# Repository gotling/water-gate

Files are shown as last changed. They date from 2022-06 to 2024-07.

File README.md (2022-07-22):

# Watergate

A growhose helper. Sensors and watering of plants with added nutrition. 

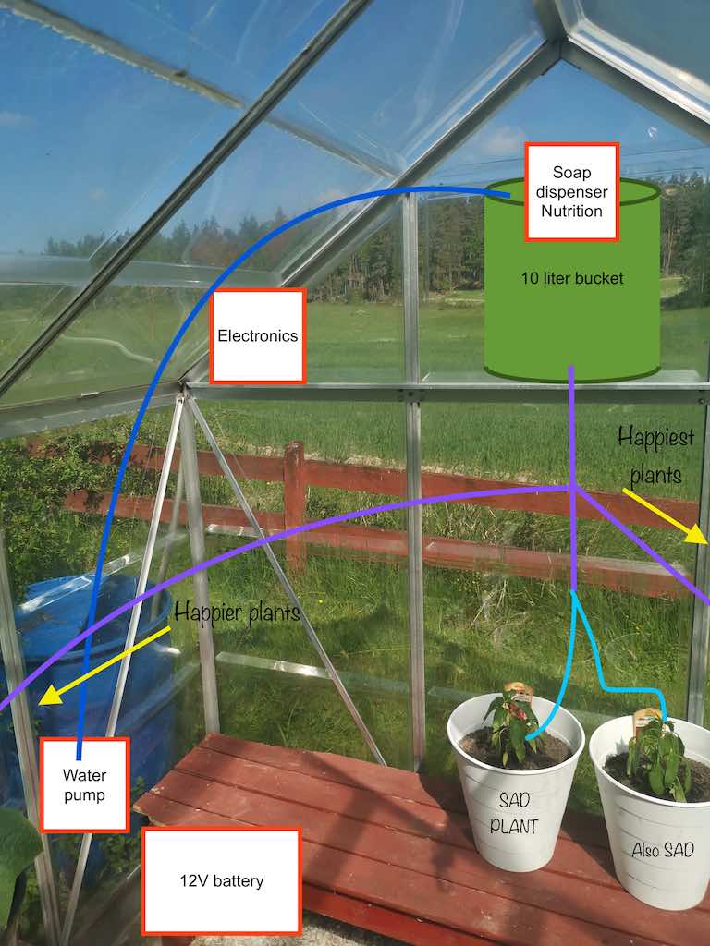
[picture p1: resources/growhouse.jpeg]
Growhouse


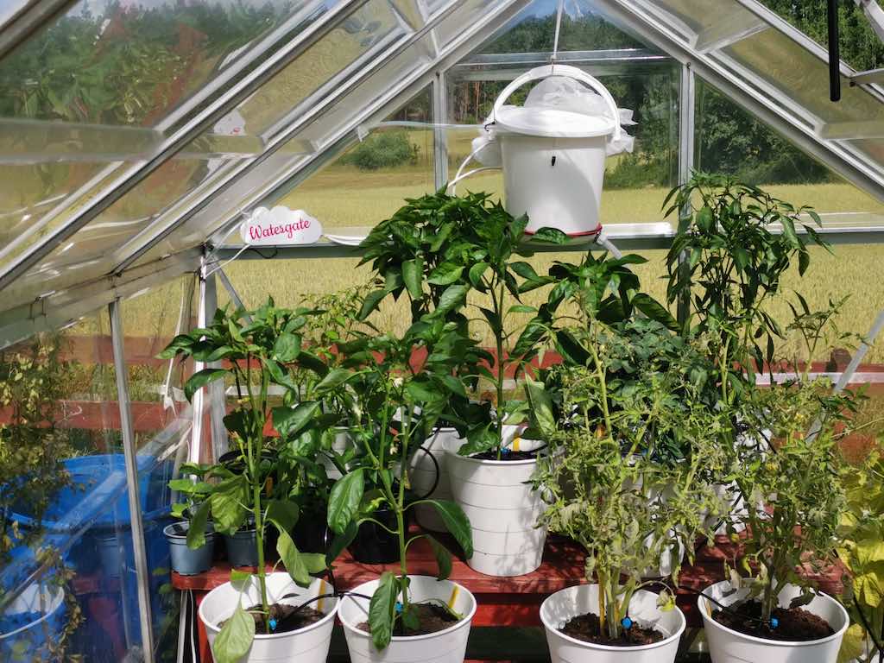
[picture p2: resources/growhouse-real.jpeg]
Growhouse Photo


# Configuration

WiFi config set using WiFi Manager by connecting to network Watergate on first boot.

**gmtOffset_sec**

Adjustment in seconds from GMT

**waterHour**

Array of hours when automatic watering should be done

## MQTT

Setup to use Adafruit IO service.

Configure username, password and topic by creating a *config.h* file with the following defines:

    #define MQTT_USER ""
    #define MQTT_PASSWORD ""
    #define MQTT_TOPIC ""

# Hardware

ESP32 devkit.

DHT22 temperature and humidity sensor.

12v AGM battery.

12v 5w water pump.

Hygrometers for measuring soil humidity.

Buck converter for getting 5v from 12v battery.

Simple voltage divider for checking battery level.

MOSFETs for controlling pump, motor and sensors.

Water level sensors.

# Schematics

First time using KiCad to help with construction.

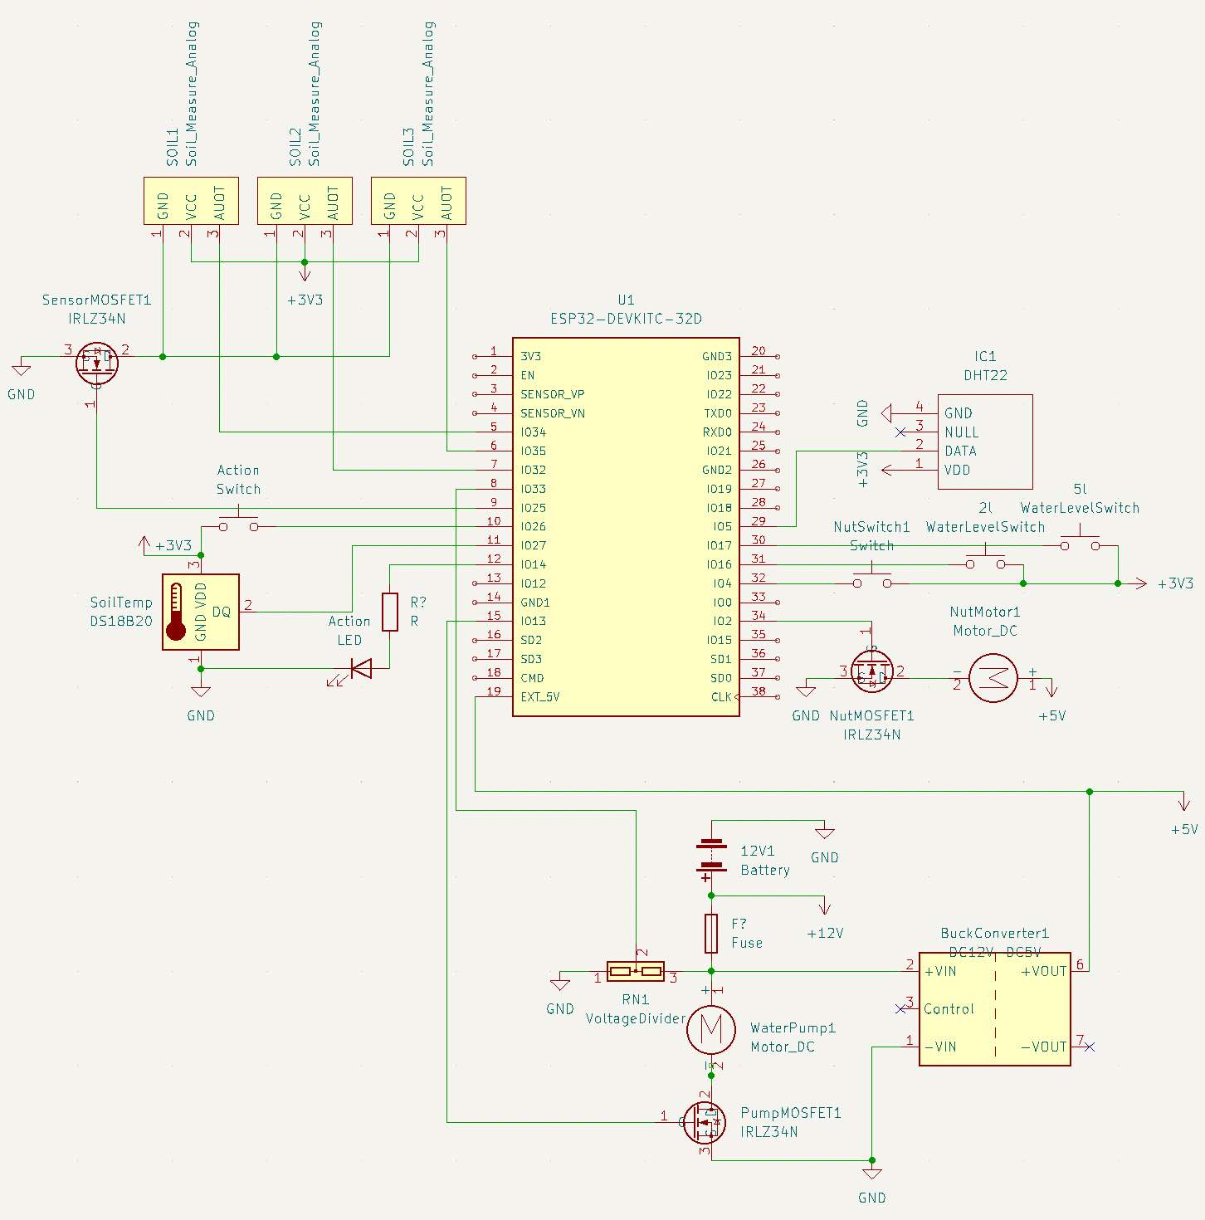
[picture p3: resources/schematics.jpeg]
Schematics


# Software

Written in Arduino IDE 2.0.

Coded in C.

# Enclosures

Made in Fusion 360 with main purpouse to protect electronics from direct sunligt.

https://a360.co/3csUwN7

# Libraries

These libraries needs to be installed in Arduino IDE to be able to build.

**FTDebouncer** by Ubi de Feo

https://github.com/ubidefeo/FTDebouncer

**DHT sensor library** by Adafruit

https://github.com/adafruit/DHT-sensor-library

**WiFiManager** by tzapu

https://github.com/tzapu/WiFiManager

**PubSubClient** by Nick O'Leary

https://github.com/knolleary/pubsubclient

**DallasTemperature** by Miles Burton

https://github.com/milesburton/Arduino-Temperature-Control-Library

**OneWire** by Jim Studt, ...

https://www.pjrc.com/teensy/td_libs_OneWire.html

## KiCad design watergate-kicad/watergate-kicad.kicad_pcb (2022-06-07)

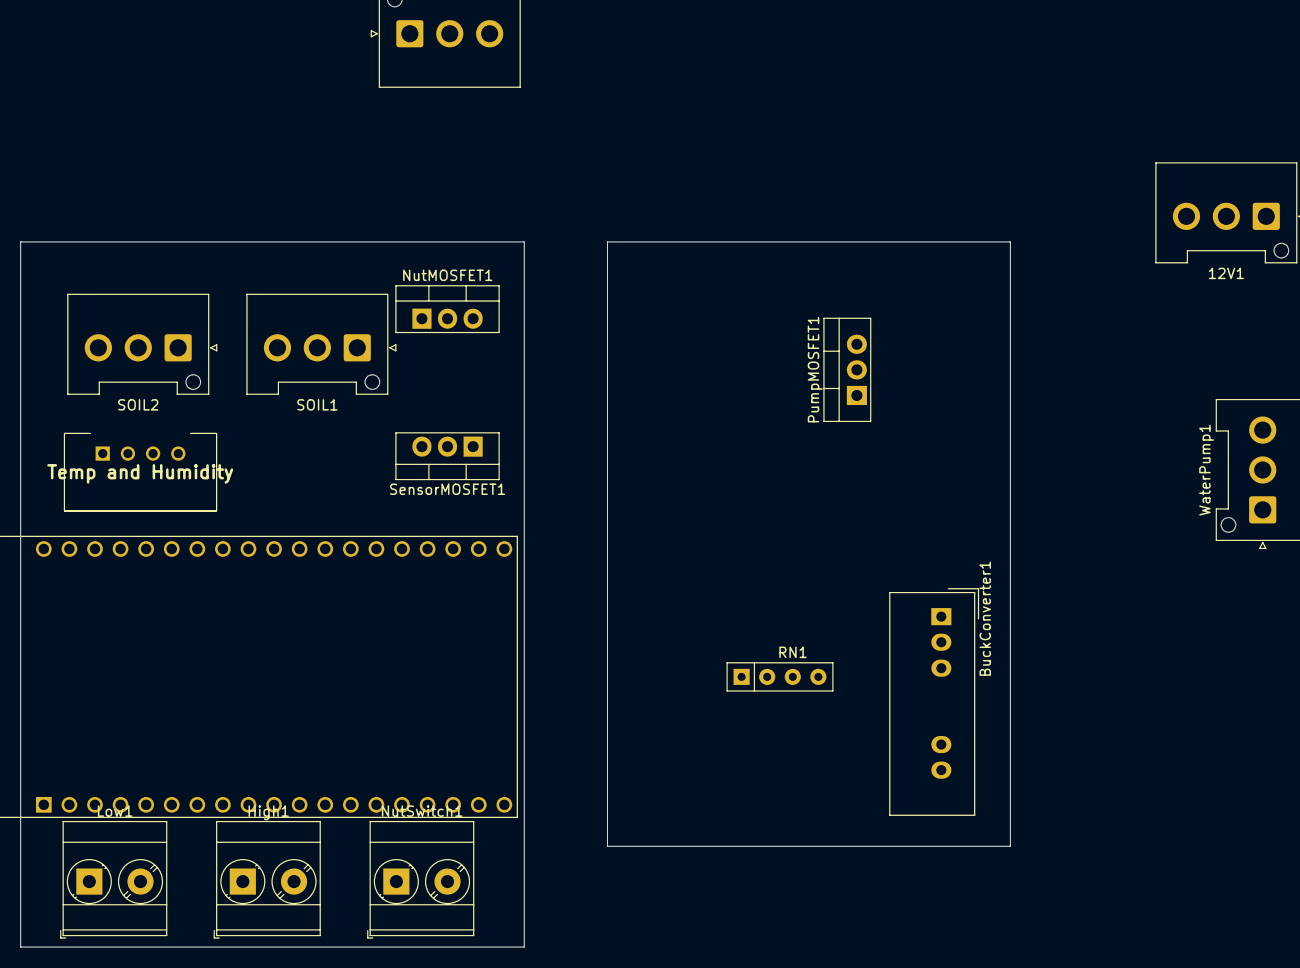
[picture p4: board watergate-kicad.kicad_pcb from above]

Board: 2 copper layers, 98.3 x 70.0 mm, 15 parts (0 on the bottom side), 18 nets, no tracks yet.

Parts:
12V1: Battery; JST_VH_B3P-VH-FB-B_1x03_P3.96mm_Vertical
BuckConverter1: DC12V-DC5V; Converter_DCDC_Murata_NCS1SxxxxSC_THT
High1: WaterLevelSwitch; TerminalBlock_Phoenix_MKDS-3-2-5.08_1x02_P5.08mm_Horizontal
Low1: WaterLevelSwitch; TerminalBlock_Phoenix_MKDS-3-2-5.08_1x02_P5.08mm_Horizontal
NutMOSFET1: IRLZ34N; TO-220-3_Vertical
NutMotor1: Motor_DC; JST_VH_B3P-VH-FB-B_1x03_P3.96mm_Vertical
NutSwitch1: Switch; TerminalBlock_Phoenix_MKDS-3-2-5.08_1x02_P5.08mm_Horizontal
PumpMOSFET1: IRLZ34N; TO-220-3_Vertical
RN1: VoltageDivider; R_Array_SIP4
SOIL1, SOIL2: Soil_Measure_Analog; JST_VH_B3P-VH-FB-B_1x03_P3.96mm_Vertical
SensorMOSFET1: IRLZ34N; TO-220-3_Vertical
Temp and Humidity: DHT22
U1: ESP32-DEVKITC-32D; MODULE_ESP32-DEVKITC-32D
WaterPump1: Motor_DC; JST_VH_B3P-VH-FB-B_1x03_P3.96mm_Vertical

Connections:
unnamed: 12V1.1 (+), BuckConverter1.2 (+VIN), RN1.3, WaterPump1.1 (+)
unnamed: 12V1.2 (-), BuckConverter1.1 (-VIN), NutMOSFET1.2 (D), PumpMOSFET1.2 (D), RN1.1, U1.14 (GND1)
unnamed: High1.1, Low1.1, NutSwitch1.1, Temp and Humidity.1 (VDD), U1.1 (3V3)
unnamed: NutMOSFET1.1 (G), NutMotor1.2 (-)
unnamed: NutMOSFET1.3 (S), U1.13 (IO12)
unnamed: BuckConverter1.6 (+VOUT), NutMotor1.1 (+), SOIL1.2 (VCC), SOIL2.2 (VCC), U1.19 (EXT_5V)
unnamed: PumpMOSFET1.1 (G), WaterPump1.2 (-)
unnamed: PumpMOSFET1.3 (S), U1.12 (IO14)
unnamed: SOIL1.1 (GND), SOIL2.1 (GND), SensorMOSFET1.1 (G)
unnamed: SOIL1.3 (AUOT), U1.31 (IO16)
unnamed: SOIL2.3 (AUOT), U1.32 (IO4)
unnamed: SensorMOSFET1.2 (D), Temp and Humidity.4 (GND), U1.20 (GND3)
unnamed: SensorMOSFET1.3 (S), U1.33 (IO0)
unnamed: High1.2, U1.9 (IO25)
unnamed: Low1.2, U1.10 (IO26)
unnamed: NutSwitch1.2, U1.11 (IO27)
unnamed: RN1.2, U1.15 (IO13)
unnamed: Temp and Humidity.2 (DATA), U1.21 (IO23)

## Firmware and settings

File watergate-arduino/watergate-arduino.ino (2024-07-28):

/**
 * Watergate - Automatic watering for growhouse
 *
 * FTDebouncer by Ubi de Feo
 * https://github.com/ubidefeo/FTDebouncer
 * DHT sensor library by Adafruit 
 * https://github.com/adafruit/DHT-sensor-library
 * DallasTemperature by Miles Burton
 * https://github.com/milesburton/Arduino-Temperature-Control-Library
 * OneWire by Jim Studt, ...
 * https://www.pjrc.com/teensy/td_libs_OneWire.html
 * WiFiManager by tzapu
 * https://github.com/tzapu/WiFiManager
 * PubSubClient by Nick O'Leary
 * https://github.com/knolleary/pubsubclient
 */

#include <FTDebouncer.h>

#include "esp_wifi.h"
#include "driver/adc.h"
#include <WiFiClientSecure.h>
#include <WiFiManager.h>
#include <PubSubClient.h>
#include <time.h>
#include "RTClib.h"

#include "config.h"
#include "globals.h"
#include "sensor.h"
#include "time_functions.h"
#include "output.h"

// Global
#define NUT_TARGET 14

// Buttons
FTDebouncer pinDebouncer;
#define BTN_NUT 4 // Green/White
#define BTN_TEST 15 // 
#define BTN_ACTION 26

// MOSFET
#define MOSFET_NUT 2 // Green
#define MOSFET_PUMP 13

// Network
//WiFiManager wm;
WiFiClientSecure client;
PubSubClient mqtt(client);

#define MQTT_SERVER "io.adafruit.com"
#define MQTT_PORT 8883
// Set the following in config.h
//#define MQTT_USER ""
//#define MQTT_PASSWORD ""
//#define MQTT_TOPIC ""

// State
bool hygroActive = false;
short readingRound = 0;
float hyg1 = 0;
float hyg2 = 0;
float hyg3 = 0;
float temperature;
short humidity;
float soilTemperature;
short analogVoltage;
float voltage;
short level = 0;

long nutCounter = 0;
bool actionPump = false;
bool actionNut = false;

typedef enum {
  MEASURING,
  WATERING
} states;

states state = MEASURING;

// Timers
unsigned long wakeTime = millis();
#define  MAX_PUMP_TIME 180000 // 3 minute
unsigned long pumpStartTime = millis();
unsigned long timeToStayAwake;
#define MAX_WAKE_TIME 600000 // 10 minutes

// Automation
short waterHour[] = { 6 };
RTC_DATA_ATTR short wateredHour = -1;

short nutritionWeekDays[] = { 1, 4 };
RTC_DATA_ATTR short nutritionAddedDay = -1;

typedef enum {
  ACTION,
  LED,
  NUT,
  PUMP,
  LEVEL,
  TIMER
} Event;

void addNutrition() {
  nutCounter = 0;
  digitalWrite(MOSFET_NUT, HIGH);
}

void pump(bool start) {
  if (start) {
    state = WATERING;
    pumpStartTime = millis();
    actionPump = true;
    digitalWrite(MOSFET_PUMP, HIGH);
    mqttSendEvent(PUMP, 1);
  } else {
    actionPump = false;
    digitalWrite(MOSFET_PUMP, LOW);
    mqttSendEvent(PUMP, 0);
  }
}

// Button pressed
void onPinActivated(int pinNumber) {
  switch (pinNumber) {
    case BTN_NUT:
      nutCounter++;
      Serial.print("Nut: ");
      Serial.println(nutCounter);
      if (nutCounter >= NUT_TARGET) {
        digitalWrite(MOSFET_NUT, LOW);
        digitalWrite(LED_ACTION, LOW);
        Serial.println("Nut: Target reached");
      }
      mqttSendEvent(NUT, nutCounter);
      break;
    case BTN_TEST:
      Serial.println("More nuts");
      digitalWrite(MOSFET_NUT, HIGH);
      break;
    case BTN_LEVEL_2L:
      Serial.println("Liquid: > 2l");
      // If nutrition should be added, do it now
      if (actionNut) {
        addNutrition();
        actionNut = false;
      }
      level = 2;
      mqttSendEvent(LEVEL, 2);
      break;
    case BTN_LEVEL_5L:
      Serial.println("Liquid: > 5l");
      // Stop pump
      pump(false);
      level = 5;
      mqttSendEvent(LEVEL, 5);
      break;
    case BTN_ACTION:
      
      // Cancel pump and nutrition
      if (actionNut) {
        Serial.println("Action: Cancel");
        
        pump(false);
        actionNut = false;
        state = MEASURING;
        
        digitalWrite(LED_ACTION, LOW);
        
        digitalWrite(MOSFET_NUT, LOW);
        mqttSendEvent(ACTION, 0);
        break;
      }

      // If already pumping
      if (actionPump) {
        Serial.println("Action: Enable nutrition");
        // Add nutrition when water level reached
        actionNut = true;
        digitalWrite(LED_ACTION, HIGH);
        mqttSendEvent(ACTION, -2);
      } else {
        // Enable pump
        Serial.println("Action: Start pump");
        pump(true);
        mqttSendEvent(ACTION, -1);
      }
      break;
  }    
}

// Button released
void onPinDeactivated(int pinNumber) {
  switch (pinNumber) {
     case BTN_LEVEL_2L:
      Serial.println("Liquid: < 2l");
      level = 0;
      mqttSendEvent(LEVEL, 0);
      wakeTime = millis();
      timeToStayAwake = WAKE_TIME_AFTER_EMPTY;
      state = MEASURING;
      break;
    case BTN_LEVEL_5L:
      Serial.println("Liquid: < 5l");
      level = 2;
      mqttSendEvent(LEVEL, 2);
      break;
    case BTN_ACTION:
      break;
  }
}

bool shouldWater(short hour) {
  // Do nothing if we already watered this hour
  if (wateredHour == hour)
    return false;

  if (hour > wateredHour)
    wateredHour = -1;


  for(int i = 0; i < sizeof(waterHour) / sizeof(waterHour[0]); i++) {
    if (waterHour[i] == hour) {
      return true;
    }
  }

  return false;
}

bool shouldAddNutrition(short weekDay) {
  // Do nothing if we already added nutrtion this day
  if (nutritionAddedDay == weekDay)
    return false;

  for(int i = 0; i < sizeof(nutritionWeekDays) / sizeof(nutritionWeekDays[0]); i++) {
    if (nutritionWeekDays[i] == weekDay) {
      return true;
    }
  }

  return false;
}

void setup() {
  // Setup Serial
  Serial.begin(115200);
  delay(1000);
  Serial.println("Ready");
  esp_wifi_start();
  esp_wifi_restore();

  // MOSFET
  pinMode(MOSFET_PUMP, OUTPUT);
  digitalWrite(MOSFET_PUMP, LOW);
  pinMode(MOSFET_NUT, OUTPUT);
  digitalWrite(MOSFET_NUT, LOW);

  // Button
  pinDebouncer.addPin(BTN_NUT, HIGH, INPUT_PULLUP);
  pinDebouncer.addPin(BTN_TEST, HIGH, INPUT_PULLUP);
  pinDebouncer.addPin(BTN_LEVEL_2L, HIGH, INPUT_PULLUP);
  pinDebouncer.addPin(BTN_LEVEL_5L, HIGH, INPUT_PULLUP);
  pinDebouncer.addPin(BTN_ACTION, HIGH, INPUT_PULLUP);
  pinDebouncer.begin();

  // LED
  ledSetup();
  ledBlink(1000);

  // Hygro, OneWire & DHT
  setupSensor();

  // Setup WiFiManager
  setupWiFi();

  // Setup NTP
  setupTime();

  // Setup RTC
  setupRTC();

  // Setup deep sleep
  bool manual = check_wakeup_reason();

  // Wake up on button press
  esp_sleep_enable_ext0_wakeup(GPIO_NUM_26, 0);

  short hour = getHour();
  short weekDay = getWeekDay();

  // Auto water if hour is correct and this is not our first boot
  if ((bootCount > 0) && shouldWater(hour) || (waterFailSafe <= 0)) {
    // TODO: Water fail safe needs to be updated now we have a working RTC
    if (waterFailSafe <= 0)
      mqttSendEvent(ACTION, 5);
    
    wateredHour = hour;

    if (shouldAddNutrition(weekDay)) {
      actionNut = true;
      nutritionAddedDay = weekDay;
    }

    pump(true);
    timeToStayAwake = WAKE_TIME_LONG;
    state = WATERING;
    waterFailSafe = AUTO_WATER_FAIL_SAFE;
    Serial.printf("Auto water of plants. Staying awake till %d seconds after water emptied\n", timeToStayAwake);
    mqttSendEvent(ACTION, 2);
  } else if (bootCount == 1) {
    timeToStayAwake = WAKE_TIME_LONG;
    Serial.printf("First boot. Staying awake for %d seconds\n", timeToStayAwake);
    mqttSendEvent(ACTION, 0);
  } else if (manual) {
    timeToStayAwake = WAKE_TIME_LONG;
    Serial.printf("Manual wakeup. Staying awake for %d seconds\n", timeToStayAwake);
  } else {
    timeToStayAwake = WAKE_TIME_SHORT;
    Serial.printf("Measurement only. Staying awake for %d seconds\n", timeToStayAwake);
    mqttSendEvent(ACTION, 1);
  }

  ledBlink(500);
}

//bool lState = HIGH;

void loop() {
  pinDebouncer.update();
  //wm.process();
  mqtt.loop();
  ledProcess();

  if (readSensor()) {
    serialLog();

    if (readingRound % 3 == 0) {
      temperature = temperature / readingRound;
      humidity = humidity / readingRound;
      voltage = voltage / readingRound;
      hyg1 = hyg1 / readingRound;
      hyg2 = hyg2 / readingRound;
      hyg3 = hyg3 / readingRound;
      soilTemperature = soilTemperature / readingRound;

      if (WiFi.status() == WL_CONNECTED) {
        ledBlink(0);
        mqttSend();
      }
    }
  }

  // Stops pump after 3 minutes if sensors has not triggered yet
  if (actionPump && (millis() - pumpStartTime >= MAX_PUMP_TIME)) {
    Serial.println("Maximum pump time exceeded");
    pump(false);
    state = MEASURING;
    mqttSendEvent(ACTION, 3);
  }

  // Stop measuring if max time exceeded
  if ((state == WATERING) && (millis() - wakeTime >= MAX_WAKE_TIME)) {
    Serial.println("Maximum wake time exceeded");
    state = MEASURING;
    mqttSendEvent(ACTION, 4);
  }

  // Time to sleep
  // TODO: Check that no action is being performed
  if ((state == MEASURING) && (millis() - wakeTime >= timeToStayAwake * 1000)) {
    mqttSendEvent(ACTION, 0);
    int seconds = secondsTillNextHour();
    // Wait a bit longer to be sure hour has changed
    seconds += 60;
    
    Serial.println("Disconnecting MQTT..");
    mqtt.disconnect();
    delay(100);

    Serial.println("Disconnecting WiFi..");
    esp_wifi_disconnect();
    delay(100);
    esp_wifi_stop();
    delay(100);
    esp_wifi_deinit();
    delay(100);

    Serial.printf("Going to sleep for %d seconds", seconds);
    Serial.flush();
    esp_sleep_enable_timer_wakeup(seconds * uS_TO_S_FACTOR);
    esp_deep_sleep_start();
  }
}

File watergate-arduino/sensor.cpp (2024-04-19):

#include "sensor.h"
#include "globals.h"

#include <DHT.h>
#include <OneWire.h>
#include <DallasTemperature.h>

DHT dht(DHTPIN, DHTTYPE);
float temperatureOffset = 0;
int humidityOffset = 0;

OneWire oneWire(ONE_WIRE_PIN);
DallasTemperature owSensors(&oneWire);

unsigned long sensorTime = millis() - SENSOR_INTERVAL;
unsigned long hygroTime = millis() - SENSOR_INTERVAL;

/**
 * Turn on power to hygro sensors in preparation for reading their values
 */
void primeHygro(bool state) {
  hygroActive = state;
  digitalWrite(HYG_VCC_PIN, hygroActive);
}

/**
 * Read value from the hygro sensors
 */
void readHygro() {
  hyg1 += hygToPercentage(analogRead(HYG_1_PIN));
  hyg2 += hygToPercentage(analogRead(HYG_2_PIN));
  hyg3 += hygToPercentage(analogRead(HYG_3_PIN));
}

/**
 * Value returned from sensor is analog between 0 (maximum) and 4095 (minimum).
 * @returns float percentage
 */
float hygToPercentage(short value) {
  return (ANALOG_MAX-value)/40.95;
}

/**
 * Read temperature and humidity from DHT sensor
 * Assignes to global variables if valid value
 */
void readTempHum() {
  float newT = dht.readTemperature();
  float newH = dht.readHumidity();
  
  if (!isnan(newT)) {
    temperature += (newT + temperatureOffset) / 100 * 100;
  }
  
  if (!isnan(newH)) {
    humidity += newH + humidityOffset;
  }

  // oneWire sensor
  owSensors.requestTemperatures();
  float newSoilTemperature = owSensors.getTempCByIndex(0);

  if (!isnan(newSoilTemperature) && newSoilTemperature > -127) {
    soilTemperature += newSoilTemperature / 100 * 100;
  }
}

/**
 * Read battery voltage and convert to float
 */
void readVoltage() {
  analogVoltage = analogRead(BATTERY_PIN);
 
  // Max 14.5 = 4096
  voltage += (float)analogVoltage / VOLTAGE_MULTIPLIER;
}

/**
 * Read level sensors. Connected pulled high so values are inverted.
 * Set global variable level or -1 if invalid value is read
 */
void readLevel() {
    short l2 = !digitalRead(BTN_LEVEL_2L);
    short l5 = !digitalRead(BTN_LEVEL_5L);

    if ((l2 == LOW) && (l5 == LOW))
      level = 0;
    else if ((l2 == HIGH) && (l5 == LOW))
      level = 2;
    else if ((l2 == HIGH) && (l5 == HIGH))
      level = 5;
    else
      level = -1; // Should not be possible
}

/**
 * Initialize DHT and OneWire
 */
void setupSensor() {
  pinMode(HYG_VCC_PIN, OUTPUT);
  digitalWrite(HYG_VCC_PIN, LOW);
  pinMode(HYG_1_PIN, INPUT);
  pinMode(HYG_2_PIN, INPUT);
  pinMode(HYG_3_PIN, INPUT);

  pinMode(BATTERY_PIN, INPUT);

  owSensors.begin();
  dht.begin();
}

/**
 * Prepare for reading of sensor data and read sensor data.
 * @returns bool true if data has been read
 */
bool readSensor() {
  // Prepare for hygro reading
  if (millis() - sensorTime >= SENSOR_INTERVAL) {
    primeHygro(true);
    hygroTime = millis();
    sensorTime = millis();
  }

  // Read temperatures and hygro after waiting for warmup
  if (hygroActive && millis() - hygroTime >= HYGRO_WARMUP_TIME) {
    readingRound++;
    if (readingRound > 3) {
      readingRound = 1;
      temperature = humidity = voltage = hyg1 = hyg2 = hyg3 = soilTemperature = 0;
    }

    readTempHum();
    readLevel();

    readHygro();
    primeHygro(false);

    readVoltage();

    return true;
  }

  return false;
}

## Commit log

2022-06-16 Add liquid level sensors
2022-06-16 Add 3 hygrometer sensors and one temperature probe
2022-06-30 Read battery voltage
2022-06-30 Wiring hints
2022-06-30 Button and LED form manual control
2022-07-18 Move pin arounds to handle ADC2 unavailable using WiFi
2022-07-18 Avoid logging invalid data from soil temp probe
    [watergate-arduino.ino]
2022-07-22 Update to reality
    [watergate-kicad.kicad_sch]
2022-07-24 Start refactoring code. Break out sensor functions
2022-07-24 Extract voltage
2022-07-24 Sensor loop
2022-08-07 Read level as part of reading sensors
2022-08-07 Fail WiFi connection after 30 seconds
    [network.ino]
2022-08-07 Separate log and led to separate file
2024-04-19 Change WiFi connect/disconnect, average sensor readings, use external RTC
